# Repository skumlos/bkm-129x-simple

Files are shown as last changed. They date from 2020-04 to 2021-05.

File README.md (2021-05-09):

A simplified version of the BKM-129X compatible board.

Should be able to be created at $25-30, with the ADG1611 being the most expensive component.

This requires an Arduino Nano v3 loaded with the latest BKM-129X-MCU code from https://github.com/skumlos/bkm-129x-mcu

For more information go to https://immerhax.com/?p=422

You are welcome to clone, produce and sell hardware based on this. Please keep changes and so on open source.

Cool kids give credit where due.

Thanks goes out to Nick Carney and Bob from RetroRGB for rigorious testing!

--------

Compatibility list and tested consoles (including issues):

PVM-9L2
- SNES (US region, CSYNC)
- Mega Drive 2 (EU region, 60 Hz modded with DFO for "true" 60 Hz, CSYNC)
- Master System 1 (EU region, 60 Hz modded with DFO for "true" 60 Hz, CSYNC)
- PC-Engine (White, with THS7374 external RGB amp, CSYNC)

BVM-D14
- Genesis 1 (60 Hz, CSYNC)

BVM-D9
- Nomad (60 Hz, Triple bypass modded, CSYNC)
- SNES (US region, CSYNC)
- Master System (60 Hz, sync issues like original 129X)
- TurboGrafx/PC-Engine (60 Hz, sync issues like original 129X)

---------

Board revision history:

D: Fix THS7374 filter bypass, move to Kicad 5

C: Rearranged some components for nicer layout

B: Added R29, R30, R31 to compensate for overbrightness

A: Changed R9 to 0 Ohm / jumper

---------

Copyright © 2020 Martin Hejnfelt <martin@hejnfelt.com>
This work is free. You can redistribute it and/or modify it under the
terms of the Do What The Fuck You Want To Public License, Version 2,
as published by Sam Hocevar. See the LICENSE file for more details.

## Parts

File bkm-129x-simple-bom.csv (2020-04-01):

Id | Designator | Package | Quantity | Designation | Supplier and ref
1 | C1,C2,C3,C4,C5,C6,C9,C12 | C_0805_HandSoldering | 8 | 0.1uF
2 | C7,C8,C13 | CP_Elec_6.3x5.3 | 3 | 100uF
3 | J1 | BNC-THT | 1 | YG1 | ADAM TECH RF1-01B-D-00-75 (but others are compatible)
4 | J2 | BNC-THT | 1 | PBB1 | ADAM TECH RF1-01B-D-00-75 (but others are compatible)
5 | J3 | BNC-THT | 1 | PRR1 | ADAM TECH RF1-01B-D-00-75 (but others are compatible)
6 | J4 | BNC-THT | 1 | SYNC1 | ADAM TECH RF1-01B-D-00-75 (but others are compatible)
7 | J5 | DIN-41612-64P | 1 | Conn_02x32_Row_Letter_Last | Amphenol T821-1-64-R1 (but any 64-pin (2x32) pin header with 2.54 mm pitch seems good)
8 | Q1 | SC-59_Handsoldering | 1 | DTC144EKA
9 | R1,R18 | R_0805_HandSoldering | 2 | 10K
10 | R2,R3,R4,R5,R14,R15,R16,R17 | R_0805_HandSoldering | 8 | R
11 | R6,R7,R8,R29,R30,R31 | R_0805_HandSoldering | 6 | 150R
12 | R9 | R_0805_HandSoldering | 1 | 0R
13 | R10,R11,R12,R13 | R_0805_HandSoldering | 4 | 75R
14 | R20,R22,R25,R27 | R_0805_HandSoldering | 4 | 100K
15 | R21,R24,R26,R28 | R_0805_HandSoldering | 4 | 100R
16 | R23,R19 | R_0805_HandSoldering | 2 | 4K7
17 | U1 | TSSOP-16_4.4x5mm_Pitch0.65mm | 1 | ADG1611
18 | U3 | arduino-nano-v3 | 1 | arduino-nano-v3
19 | U2 | TSSOP-14_4.4x5mm_Pitch0.65mm | 1 | THS7374
20 | U4 | TSSOP-14_4.4x5mm_Pitch0.65mm | 1 | 74VHC125 | Note 74VHC125
21 | C10 | C_0805_HandSoldering | 1 | 2.2uF
22 | C11 | C_0805_HandSoldering | 1 | 1uF
23 | U5 | SOT-23-5_HandSoldering | 1 | MIC3490-3.3

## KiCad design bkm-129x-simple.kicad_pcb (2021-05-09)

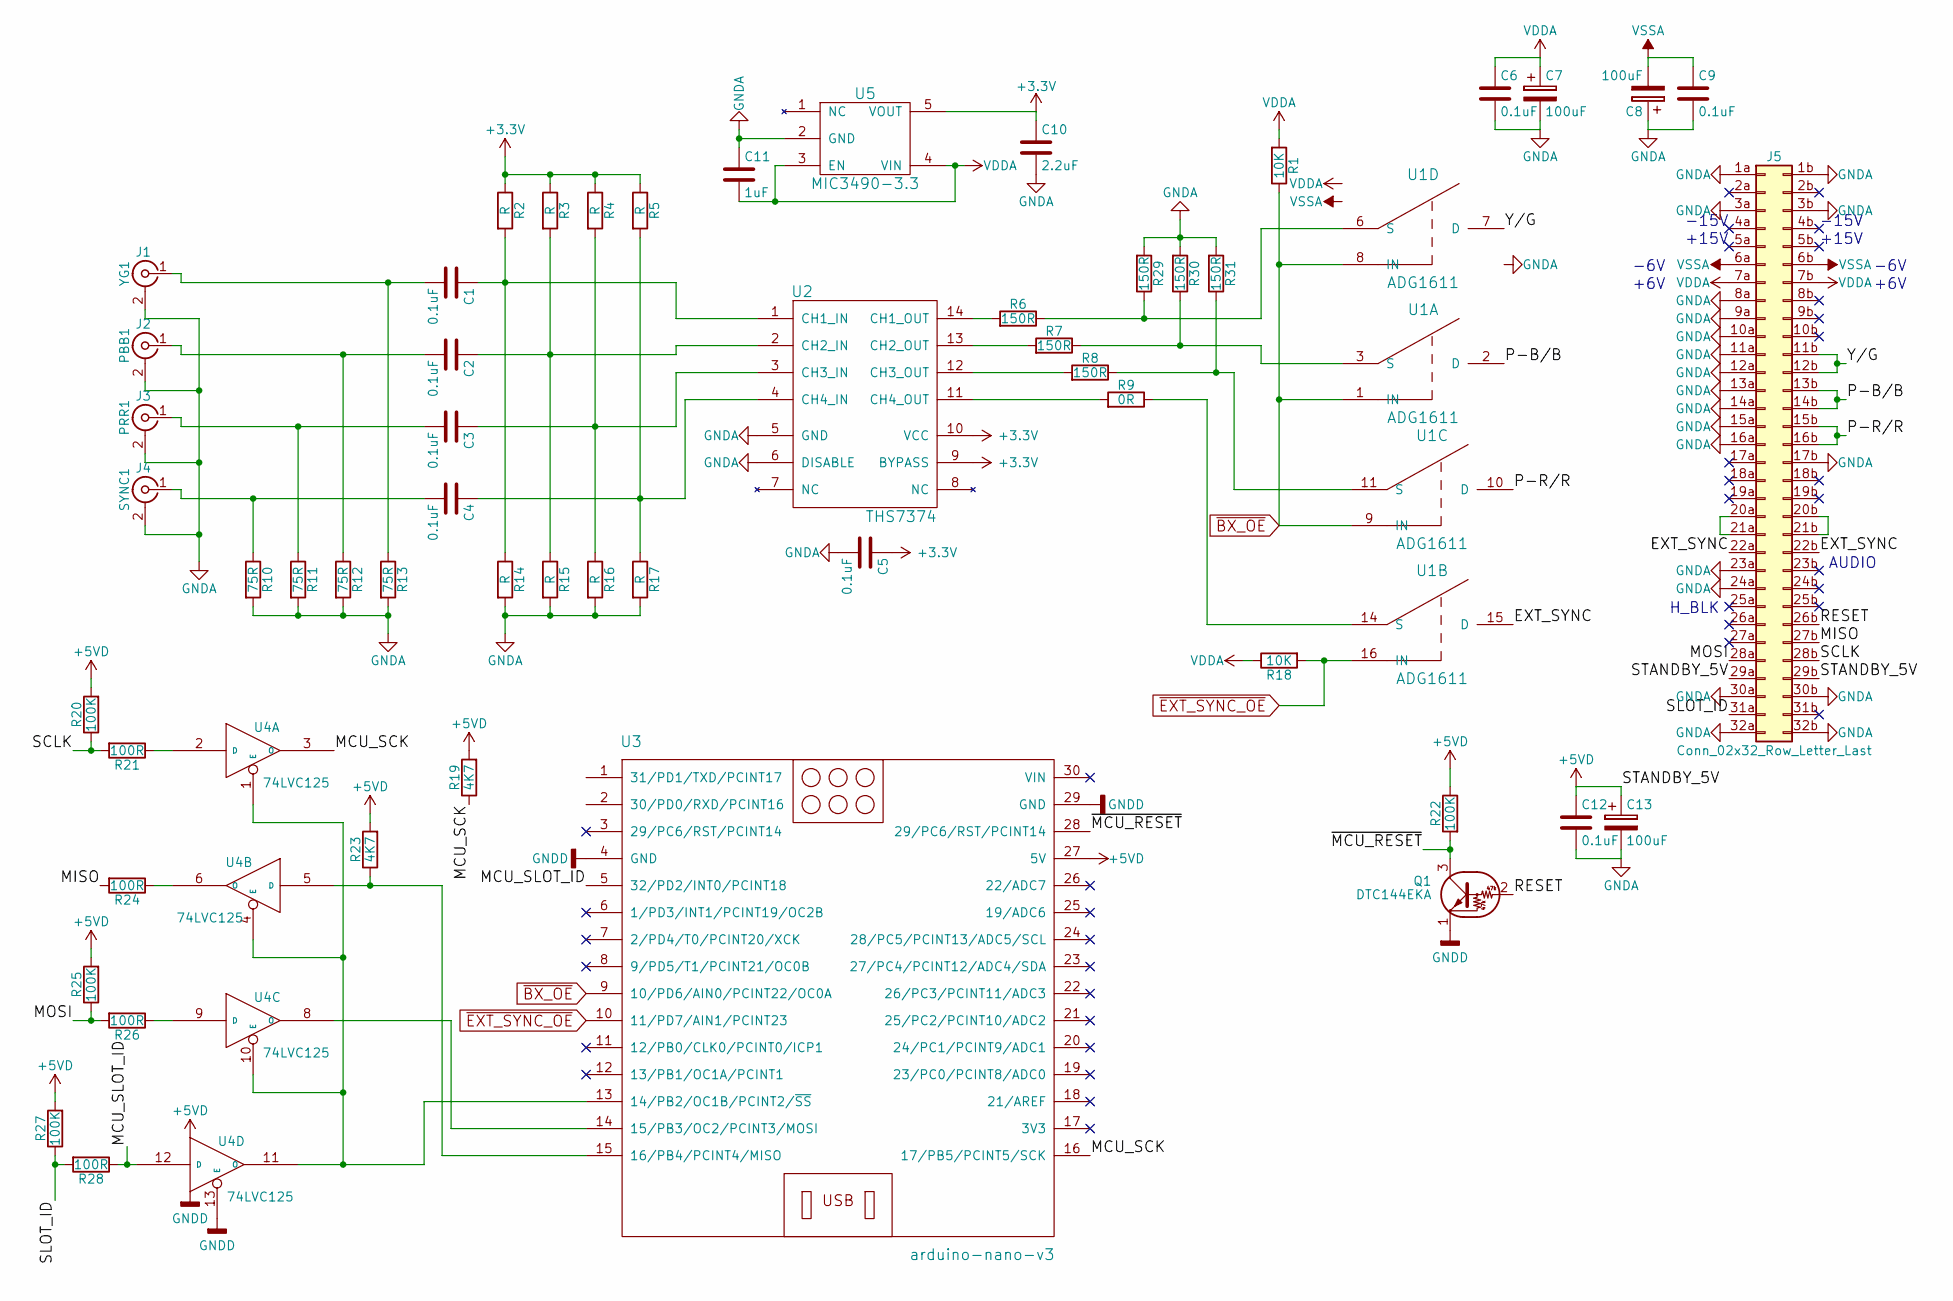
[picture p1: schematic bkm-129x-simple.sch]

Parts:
C1, C2, C3, C4, C5, C6, C9, C12: 0.1uF; C_0805_HandSoldering
C7, C8, C13: 100uF; CP_Elec_6.3x5.3
C10: 2.2uF; C_0805_HandSoldering
C11: 1uF; C_0805_HandSoldering
J1: YG1; BNC-THT
J2: PBB1; BNC-THT
J3: PRR1; BNC-THT
J4: SYNC1; BNC-THT
J5: Conn_02x32_Row_Letter_Last; DIN-41612-64P
Q1: DTC144EKA; SC-59_Handsoldering
R1, R18: 10K; R_0805_HandSoldering
R2, R3, R4, R5, R14, R15, R16, R17: R; R_0805_HandSoldering
R6, R7, R8, R29, R30, R31: 150R; R_0805_HandSoldering
R9: 0R; R_0805_HandSoldering
R10, R11, R12, R13: 75R; R_0805_HandSoldering
R19, R23: 4K7; R_0805_HandSoldering
R20, R22, R25, R27: 100K; R_0805_HandSoldering
R21, R24, R26, R28: 100R; R_0805_HandSoldering
U1: ADG1611; TSSOP-16_4.4x5mm_Pitch0.65mm
U2: THS7374; TSSOP-14_4.4x5mm_Pitch0.65mm
U3: arduino-nano-v3
U4: 74LVC125; TSSOP-14_4.4x5mm_Pitch0.65mm
U5: MIC3490-3.3; SOT-23-5_HandSoldering

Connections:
+3V3: C5.1, C10.1, R2.1, R3.1, R4.1, R5.1, U2.9 (BYPASS), U2.10 (VCC), U5.5 (VOUT)
+5VD: C12.1, C13.1, J5.29a, J5.29b, R19.2, R20.2, R22.1, R23.2, R25.2, R27.2, U3.27 (5V), U4.14 (VCC)
/EXT_SYNC: J5.22a, J5.22b, U1.15 (D)
/MCU_SCK: R19.1, U3.16 (17/PB5/PCINT5/SCK), U4.3 (O)
/MCU_SLOT_ID: R28.1, U3.5 (32/PD2/INT0/PCINT18), U4.12 (D)
/MISO: J5.27b, R24.2
/MOSI: J5.28a, R25.1, R26.2
/P-B/B: J5.13b, J5.14b, U1.2 (D)
/P-R/R: J5.15b, J5.16b, U1.10 (D)
/RESET: J5.26b, Q1.2 (B)
/SCLK: J5.28b, R20.1, R21.2
/SLOT_ID: J5.31a, R27.1, R28.2
/Y/G: J5.11b, J5.12b, U1.7 (D)
/~MCU_RESET: Q1.3 (C), R22.2, U3.28 (29/PC6/RST/PCINT14)
unnamed: C1.1, R2.2, R14.1, U2.1 (CH1_IN)
unnamed: C1.2, J1.1 (In), R13.1
unnamed: C2.1, R3.2, R15.1, U2.2 (CH2_IN)
unnamed: C2.2, J2.1 (In), R12.1
unnamed: C3.1, R4.2, R16.1, U2.3 (CH3_IN)
unnamed: C3.2, J3.1 (In), R11.1
unnamed: C4.1, R5.2, R17.1, U2.4 (CH4_IN)
unnamed: C4.2, J4.1 (In), R10.1
unnamed: J5.20a, J5.21a
unnamed: J5.20b, J5.21b
unnamed: R6.2, U2.14 (CH1_OUT)
unnamed: R7.2, U2.13 (CH2_OUT)
unnamed: R8.2, U2.12 (CH3_OUT)
unnamed: R9.1, U1.14 (S)
unnamed: R9.2, U2.11 (CH4_OUT)
unnamed: R21.1, U4.2 (D)
unnamed: R23.1, U3.15 (16/PB4/PCINT4/MISO), U4.5 (D)
unnamed: R24.1, U4.6 (O)
unnamed: R26.1, U4.9 (D)
unnamed: R6.1, R29.1, U1.6 (S)
unnamed: R7.1, R30.1, U1.3 (S)
unnamed: R8.1, R31.1, U1.11 (S)
unnamed: U3.13 (14/PB2/OC1B/PCINT2/~SS), U4.1 (E), U4.4 (E), U4.10 (E), U4.11 (O)
unnamed: U3.14 (15/PB3/OC2/PCINT3/MOSI), U4.8 (O)
VDD: C6.1, C7.1, C11.2, J5.7a, J5.7b, R1.2, R18.1, U1.13 (VDD), U5.3 (EN), U5.4 (VIN)
VSS: C8.2, C9.1, J5.6a, J5.6b, U1.4 (VSS)
~BX_OE: R1.1, U1.1 (IN), U1.8 (IN), U1.9 (IN), U3.9 (10/PD6/AIN0/PCINT22/OC0A)
~EXT_SYNC_OE: R18.2, U1.16 (IN), U3.10 (11/PD7/AIN1/PCINT23)

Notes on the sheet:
-15V
+15V
-6V
+6V
AUDIO
H_BLK

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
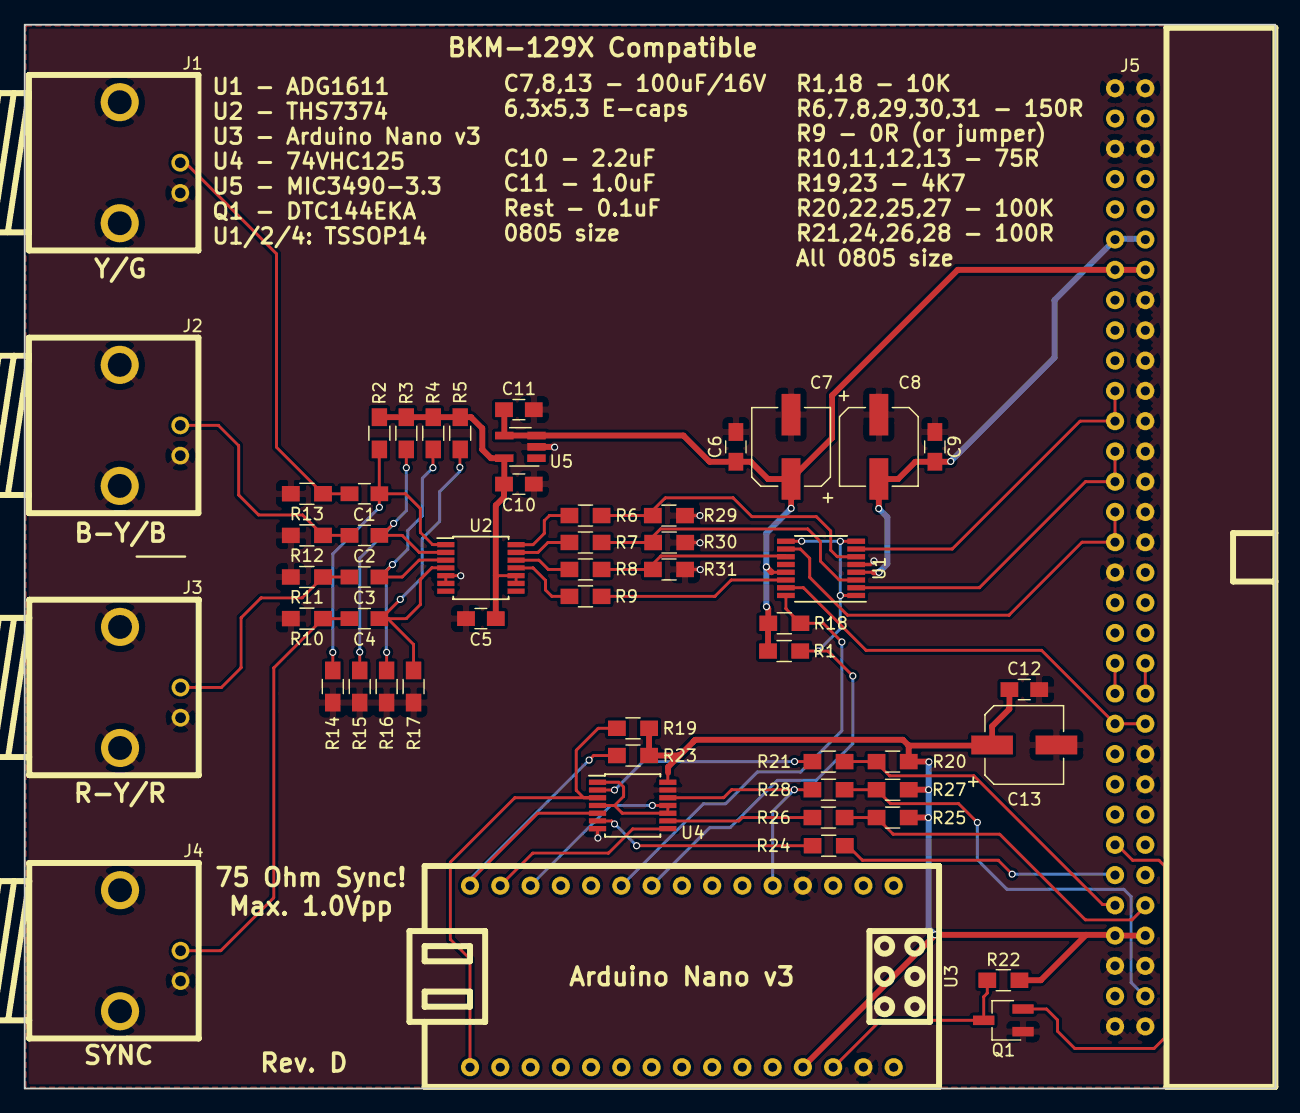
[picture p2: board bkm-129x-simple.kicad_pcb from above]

Board: 2 copper layers, 105.0 x 89.3 mm, 55 parts (0 on the bottom side), 43 nets.

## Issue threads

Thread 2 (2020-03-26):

Brighter than stock inputs on a 20L5

tianfeng33, 2020-03-26:
I took a look the schematics and I am note sure what values or level is expected at the card pins.  I put it  on the scope and with 75 ohm termination and rgb is at 320mv to the rear pins. The video is definitely brighter than a direct input to the monitor.

skumlos, 2020-03-26:
Yes this is also my experience on the L2 (that it is slightly brighter than expected, as there are no stock inputs to compare with) as I have to lower brightness a little. I have however not found it in any way "overbright" (if that's even a word). Since video goes into a transistor and they are current controlled, not voltage, the whole deal must be depending on the resistors after the THS7374. I tried fiddling a bit with them, but much higher than 150 Ohm, and I wouldn't get a picture at all. Since this boards as such is completely different to the original board in regards to the video signal paths, I guess it is "expected" to vary. Any insights to changes that alleviates the brightness difference, is of course welcome :)

skumlos, 2020-03-26:
I guess this also means the board seemingly works on L5 units, right?

tianfeng33, 2020-03-26:
100% working on a 20L5.  I am going to swap the he 75 ohm termination on the inputs to 68 and that should drop the input to the 7374.  Let’s see what happens and I will report back.

skumlos, 2020-03-26:
Hmm that shouldn't change much, unless you put a resistor in front also, to make a voltage divider. You'd then just be terminating with a wrong value. I think I'd try to find something like a ~160 Ohm and replace after the THS (except at R9 which should be 0). But I'll await your findings :)

tianfeng33, 2020-03-26:
We don’t need to terminate the signal because we are amping it again.  There is already a voltage divider in the circuit with the 75 ohms impedance of the cables.  After some trial and error the best value I found was 27ohms.  Switching back and forth I can’t see a difference.

skumlos, 2020-03-26:
Hmm, I will admit that I am no analog engineer, but as far as I know, the termination should match transmission line impedance, to avoid reflections and thus image distortion in this case. I would still prefer to fix this post-amplification. I'll try to solder up a board and see how I can change the outcome, by fiddling more with the R6/7/8.

tianfeng33, 2020-03-26:
Sounds good. I get that impedance matching is important but the overly bright picture was much more problematic in my estimation. I scoped the output pins and the signals are very clean.   Let me know what you figure out. I am willing to test and help out.

skumlos, 2020-03-26:
Cool! But when you say overly bright, it was like *definitely* noticable (because I for sure didn't see it as bad on the L2)? And I haven't heard others mention this. Maybe I should take my two L2s, original 129X in one, and then passthrough to the compatible and see how it looks. I guess that's the closest I can get to a reference, as the L2 otherwise has no RGB in.

tianfeng33, 2020-03-26:
So I have a an extron cross point hooked up and my consoles are bypassed so they are measuring at just under 700mv on rgb. I can set the output to both the monitor and the card and switch back and forth.  In my estimation it was somewhere between 200 or 300mv too bright.  I had a previously overdrive rgb circuit driving the signals to 850mv and the card difference was brighter than that.

skumlos, 2020-03-26:
This sounds somewhat familiar. The THS7374 mentions a 300mV voltage shift on the output to compensate to sync tip. That's why I put these surroundin not-mounted resistors in, because IIRC, they have something to do with this. I guess I need to dive into the datasheet to check this out.

tianfeng33, 2020-03-26:
I was thinking that earlier but I am not sure that still is the case with ac coupling on the inputs but who knows.  Let me know what you end up trying.  Always here to help.

skumlos, 2020-04-01:
So, I got some BNC cables so I could make a passthrough from the original BKM-129X to the compatible, and see them side by side. I have two PVM-9L2 monitors, and they're from the same age, and should have roughly the same usage. The original BKM-129X is (in my opinion) much more dull in colors than the compatible. Now I have not recapped the original card, and don't know if this would make a difference. However the compatible for sure is more bright and vibrant, and maybe a bit too oversaturated. It seems not to be a problem with brightness, more contrast, as if I turned down contrast I could make them appear very similar, albeit very dull. I thus started to fiddle with the resistors after the THS7374, and I must've made some mistake in my initial tests some time ago. At that time, I tried with 200 Ohm, but then I got no picture at all. I attributed this to that the THS7374 couldn't supply enough current to turn on the transistor, but I now retried with 270 Ohm, and it worked fine. I then started raising the resistor value and with 390 Ohm there's a picture, but it's severely degraded. I didn't have anything between 300 and 390, so I tried 300, and I guess this actually gives a bit more "natural" picture. I "feel" that I now don't have to turn the brightness down to retain a pleasant picture, so I guess this might be better. I'd like to try something in between, 330 maybe, so I'll see if I can dig some up. Anyways, that's about as far as I've gotten. Maybe you can try something alike, to see how it pleases your eyes. I will say though, I *really* feel the picture of the compatible is much prettier than the original, I guess this is maybe because it's the first time I've seen them heads on like this.

tianfeng33, 2020-04-01:
Interesting.  I am using the built in inputs for rgb and component in the 20l5 so I consider them to be the standard. I I ave lots of 330s kicking around and I will give it a try

tianfeng33, 2020-04-01:
330 is still significantly brighter

skumlos, 2020-04-01:
Hmm, if I start the 240p test suite, then take the 100 IRE, turn it to 0, which I guess should be black, then switch to another input (with nothing attached, I have a hard time seeing a difference (I cant, I tried in a completely dark room). But I dunno if it makes it harder to see on a 9". On the original 129X, 100 IRE looks more gray to me than 100 IRE on the compatible which really looks *white*...  Does the 20L5 have different settings per channel? On my monitor I have the knobs, but then I also have brightness and contrast in the menu.

tianfeng33, 2020-04-01:
The are the same on both inputs.  I double checked to be sure.  When you switch inputs does your monitor display white text on the screen?  In the 240p test suite you can go to the colour bar page and match that White to the white on the page.  You can see a significant difference in the brightness of the whites on the input card where as the monitor inputs match perfectly.

skumlos, 2020-04-01:
Yeah, the whites of the text and the whites of the bkm-129x match perfectly, as where the white from the compatible is much *whiter* than the original. Hmmm...

skumlos, 2020-04-01:
Looking at the service manual, it mentions 0.6Vpp signals after the original output stages.

skumlos, 2020-04-01:
OK, to fix this, simply put a 150 Ohm resistor from the already present 150 Ohm resistors of R6/7/8, and tie it to GND. The brightness then matches very close as far as I can see. Looks like ass, works a charm :) Use whatever close GND point you have.

tianfeng33, 2020-04-01:
Calibrate those systems.  a proper 700mv rgb signal will look fantastic.

skumlos, 2020-04-01:
Nono, I mean the circuit looks like ass, when smearing a THT resistor on. The picture looks fine :)

skumlos, 2020-04-01:
Lemme hear when you try it. I can almost literally not read the OSD text anymore because they're so alike ;) I'll do a hardware revision with this in ASAP.

tianfeng33, 2020-04-01:
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 all done and looks good.  I would call that successful.

skumlos, 2020-04-01:
Nice! Thanks for your help and feedback! Appreciated :)

tianfeng33, 2020-04-01:
Now here is the question, does it even need the 7374 at all?

skumlos, 2020-04-01:
In this simplified version with no pass-throughs, I would think no. I simply tried to take the original functionality and simplify it as much as possible, meaning it basically does what the original card does, buffering and switching but with fewer components. Mind that this board was created in like 3 hours, mostly as a proof of concept, because the real sauce lies in the MCU part. However, passthroughs were meant to be added, and thus here we are :)

tianfeng33, 2020-04-01:
Awesome.  Well it seems to work well now and the issues is resolved. I’ll probably grab another one for my other slot later.

Closed 2020-04-01.

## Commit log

2020-02-17 Added readme and some info on silkscreen
    [bkm-129x-simple.kicad_pcb]
2020-02-19 Updated and fixed silkscreen BOM
    [bkm-129x-simple.kicad_pcb]
2020-02-19 Fixed more BOM mistakes
    [bkm-129x-simple.kicad_pcb]
2020-02-19 Fixed MIC3940 -> MIC3490
    [bkm-129x-simple.kicad_pcb, bkm-129x-simple.sch]
2020-03-16 Added revision, compatibility and credits
    [bkm-129x-simple.kicad_pcb, bkm-129x-simple.sch]
2020-03-18 Fixed R9 to 0 Ohm on PCB also
    [bkm-129x-simple.kicad_pcb]
2020-03-18 Added BOM
    [bkm-129x-simple-bom.csv]
2020-04-01 Added overbrightness fix
    [bkm-129x-simple.kicad_pcb, bkm-129x-simple.sch]
2020-04-01 Board revision B
2020-04-01 Updated BOM
    [bkm-129x-simple-bom.csv]
2020-06-28 Rearranged some components, bumped to rev. C
    [bkm-129x-simple.kicad_pcb]
2021-05-09 Rev. D: THS7374 LPF, Kicad 5
    [bkm-129x-simple.kicad_pcb, bkm-129x-simple.sch]
2021-05-09 Add plot
    [bkm-129x-simple-B.Cu.gbr, bkm-129x-simple-B.Mask.gbr, bkm-129x-simple-B.SilkS.gbr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]
